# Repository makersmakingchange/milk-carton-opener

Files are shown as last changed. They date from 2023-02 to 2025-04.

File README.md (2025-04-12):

# Milk Carton Opener
The Milk Carton Opener is a 3D printed aid that enables users with limited grip strength to open tetra pak cartons, including 2L cartons such as the ones used for milk and juice.

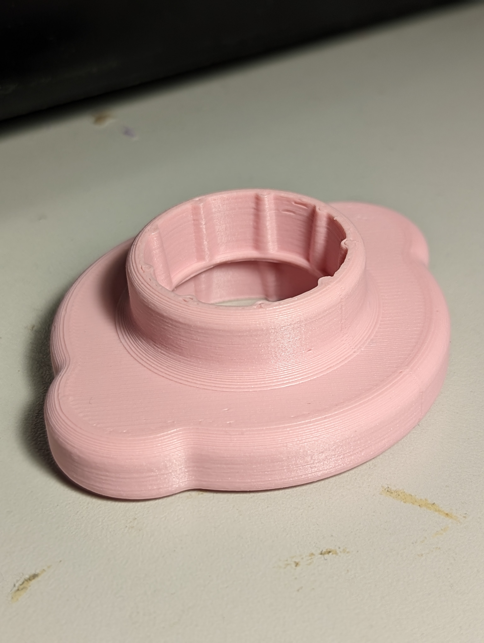
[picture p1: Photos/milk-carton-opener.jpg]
A pink 3-D printed Milk Carton Opener resting on a table.
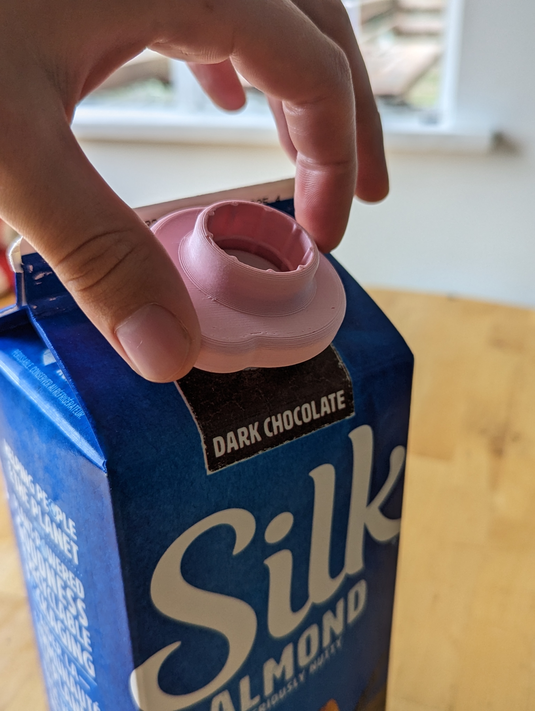
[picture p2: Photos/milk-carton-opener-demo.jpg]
Someone holding the Milk Carton Opener in their hand to remove the cap of a milk carton.
 

## More info at
- [Makers Making Change Project Page](https://makersmakingchange.com/project/milk-carton-opener/)

## How to Obtain a Milk Carton Opener
### 1. Do it Yourself (DIY) or Do it Together (DIT)

This is an open-source assistive technology, so anyone is free to build it. All of the files and instructions required to build the Milk Carton Opener are contained within this repository. Refer to the Maker Checklist below.

### 2. Request a build of this device

If you would like to obtain a Milk Carton Opener , you may submit a build request through the [MMC Library Page](https://makersmakingchange.com/project/milk-carton-opener/). The requestor is responsible for the cost of materials and any shipping.

### 3. How to build this device for someone else

If you have the skills and equipment to build this device, and would like to donate your time to create the switch for someone who needs it, visit the [MMC Maker Wanted](https://makersmakingchange.com/maker-wanted/) section.

## Getting Started

### 1. Read the Makers Checklist

The Makers' Checklist provides an overview of the necessary steps to build the device. 

### 2. Order the Off-The-Shelf Components

The [Bill of Materials](/Documentation/Milk_Carton_Opener_BOM_V1.0.xlsx) lists all of the parts and components required to print the Milk Carton Opener. 

### 3. Print the 3D Printable components

All of the files and individual print files can be in the [/Build_Files/3D_Printing_Files](/Build_Files/3D_Printing_Files/) folder.

### 4. Assemble the Milk Carton Opener

Reference the [Assembly Guide](/Documentation/Milk_Carton_Opener_Assembly_Guide_V1.0.pdf) for the tools and steps required to build each portion.

## Files
### Documentation
| Document | Version | Link |
|---|---|---|
| Design Rationale | 1.0 | [Milk_Carton_Opener_Design_Rationale](/Documentation/Milk_Carton_Opener_Design_Rationale_V1.0.pdf) |
| Maker Checklist | 1.0 | [Milk_Carton_Opener_Maker_Checklist](/Documentation/Milk_Carton_Opener_Maker_Checklist_V1.0.pdf) |
| Bill of Materials | 1.0 | [Milk_Carton_Opener_Bill_of_Materials](/Documentation/Milk_Carton_Opener_BOM_V1.0.xlsx) |
| 3D Printing Guide | 1.0 | [Milk_Carton_Opener_3D_Printing_Guide](/Documentation/Milk_Carton_Opener_3D_Printing_Guide_V1.0.pdf) |
| Assembly Guide | 1.0 | [Milk_Carton_Opener_Assembly_Guide](/Documentation/Milk_Carton_Opener_Assembly_Guide_V1.0.pdf) |
| User Guide | 1.0 | [Milk_Carton_Opener_User_Guide](/Documentation/Milk_Carton_Opener_User_Guide_V1.0.pdf) |
| Changelog | 1.0 | [Milk_Carton_Opener_Changelog](/Documentation/Milk_Carton_Opener_Changelog_V1.0.pdf) |

### Design Files
 - [CAD Files](/Design_Files)

### Build Files
 - [3D Printing Files](/Build_Files/3D_Printing_Files)

## Attribution
- Design by Tony Glynn
- Documentation by Neil Squire Society/Makers Making Change

## License

Everything needed or used to design, make, test, or prepare the Milk Carton Opener is licensed under the [Attribution-NonCommercial-ShareAlike 4.0 ](https://creativecommons.org/licenses/by-nc-sa/4.0/).

---
<!-- ABOUT MMC START -->
## About Makers Making Change
[Makers Making Change Logo](https://www.makersmakingchange.com/)

Makers Making Change is a program of [Neil Squire](https://www.neilsquire.ca/), a Canadian non-profit that uses technology, knowledge, and passion to empower people with disabilities.

Makers Making Change leverages the capacity of community based Makers, Disability Professionals and Volunteers to develop and deliver affordable Open Source Assistive Technologies.

 - Website: [www.MakersMakingChange.com](https://www.makersmakingchange.com/)
 - GitHub: [makersmakingchange](https://github.com/makersmakingchange)
 - Bluesky: [@makersmakingchange.bsky.social](https://bsky.app/profile/makersmakingchange.bsky.social)
 - Instagram: [@makersmakingchange](https://www.instagram.com/makersmakingchange)
 - Facebook: [makersmakechange](https://www.facebook.com/makersmakechange)
 - LinkedIn: [Neil Squire Society](https://www.linkedin.com/company/neil-squire-society/)
 - Thingiverse: [makersmakingchange](https://www.thingiverse.com/makersmakingchange/about)
 - Printables: [MakersMakingChange](https://www.printables.com/@MakersMakingChange)

### Contact Us
For technical questions, to get involved, or to share your experience we encourage you to [visit our website](https://www.makersmakingchange.com/) or [contact us](https://www.makersmakingchange.com/s/contact).
<!-- ABOUT MMC END -->

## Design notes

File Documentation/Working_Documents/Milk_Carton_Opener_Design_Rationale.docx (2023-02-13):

# Introduction

The Milk Carton Opener allows users with limited grip strength to open plastic 2L cartons such as the ones used for milk and juice.

# Research

Name | Picture | Price | Link

Commercial

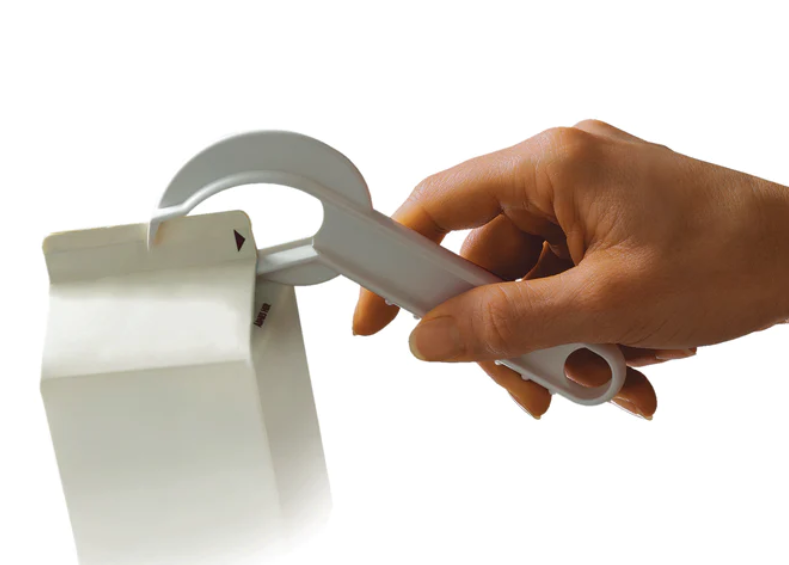
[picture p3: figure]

Tip Top Carton Opener | | $7.99 USD | Link (https://aidsforarthritis.com/products/tip-top-carton-opener)

DIY

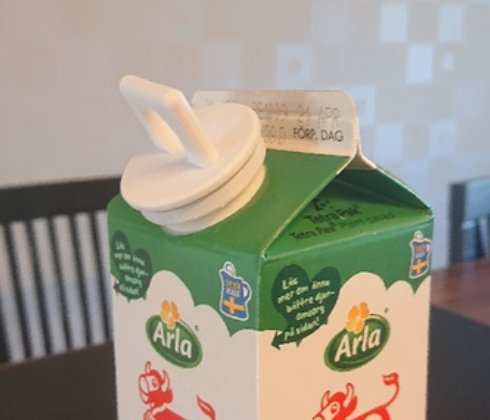
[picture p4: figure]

Milk Carton Opener | | N/A | Link (https://www.thingiverse.com/thing:4839483)

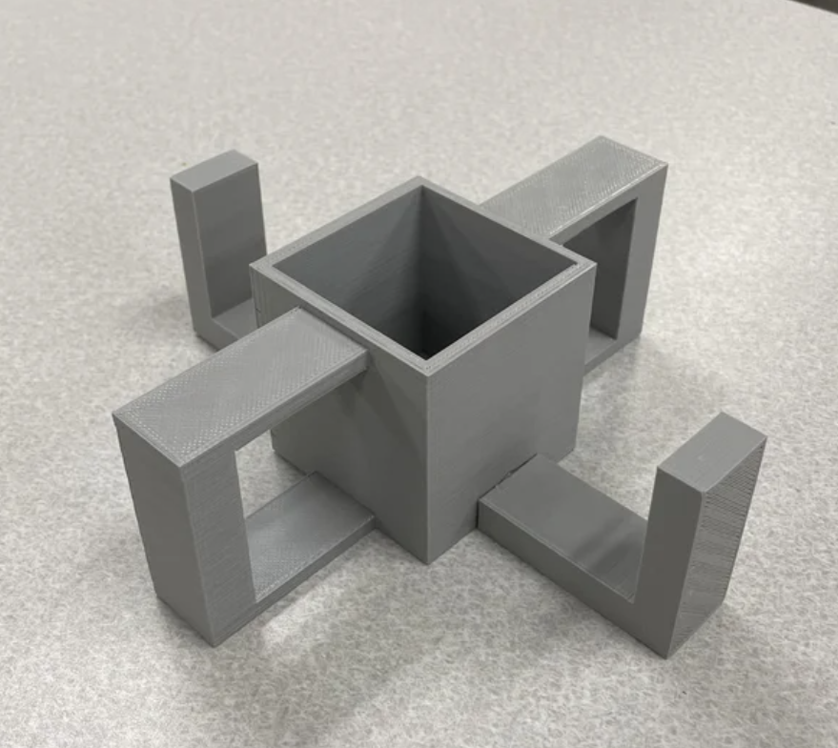
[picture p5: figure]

Milk Carton Opener | | N/A | Link (https://www.instructables.com/Milk-Carton-Opener/)

# Requirements

## Goals

G01 | Allow users with limited grip strength to open plastic milk cartons with twist off lids

## Functional Requirements

F01 | Work with both styles of plastic carton lids
F02 | Allow the lids to be removed with less force
F03 | Provide a better grip than the round lids of a carton

## Constraints

C01 | Must be entirely 3D printed

# Milk Carton Opener V1.0

## Design

This version of the design consists of a single 3D printed component with an outer handle and two differently sized gripping surfaces. The outside handle portion is cylindrical with two elongated portions to provide a gripping portion for the user’s hands. The inner gripping portions of the aids are slightly conical with rounded ribs around the periphery to provide better engagement with the screw cap.

## Print Testing

This design was test printed on a Prusa MK3S in PLA filament without support. The print was successful, though the inner portion has a bit of an unsupported lip and printed with poorer quality.

## Functional Testing

The device was tested on a Chocolate Silk Almond milk carton, and was easily able to remove the lid of the carton.

## Opportunities for Improvement

- Replace fillets on surface that lies on print bed with chamfer or mixed chamfer-fillet to improve print quality.
- Reconfigure geometry of the inner lip so device prints without support

© 2023 by Neil Squire. This work is licensed under the CC BY SA 4.0 License: http://creativecommons.org/licenses/by-sa/4.0 Files available at https://makersmakingchange.com/project/milk-carton-opener/ Page 1 of 1

V1.0 | January 2023 Milk Carton Opener Design Rationale

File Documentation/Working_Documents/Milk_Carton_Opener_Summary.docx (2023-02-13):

# Title

Milk Carton Opener

## Subtitle

An aid for people with limited grip strength to make it easier to open screwcap lids.

## Device Details

### Overview

The Milk Carton Opener is an aid to make it easier to open screwcap lids, such as those found on Tetra Pak cartons of milk, juice, and stock. This may be useful for people with limited dexterity or grip strength. The aid has two sides that fit two different sizes of cap.

### Usage

To use the device, place the hole in the device over the lid of the carton. This will provide a larger grip for the user on the lid of the carton so less grip force is required to open the lid.

### Cost

<$1

### Build Instructions

#### Skills Required

- 3D printing

#### Time Required

- 3D printing time: 1h46min
- Assembly time: None

#### Tools

- 3D printer
- Hobby knife

#### Components

- 1x Milk Carton Opener

### Attribution

- Design by Tony Glynn
- Documentation by Neil Squire Society/Makers Making Change

© 2023 by Neil Squire. This work is licensed under the CC BY SA 4.0 License: http://creativecommons.org/licenses/by-sa/4.0 Files available at https://makersmakingchange.com/project/milk-carton-opener/ Page 1 of 1

V1.0 | January 2023 Milk Carton Opener Summary

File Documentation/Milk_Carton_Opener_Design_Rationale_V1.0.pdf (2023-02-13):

V1.0 | January 2023

## Milk Carton Opener

## DESIGN RATIONALE

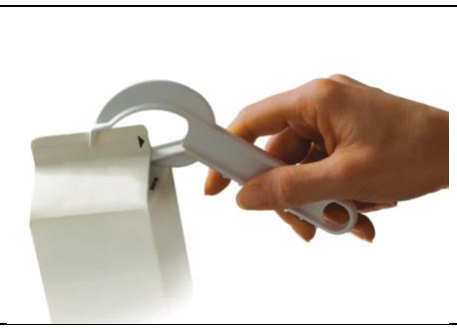
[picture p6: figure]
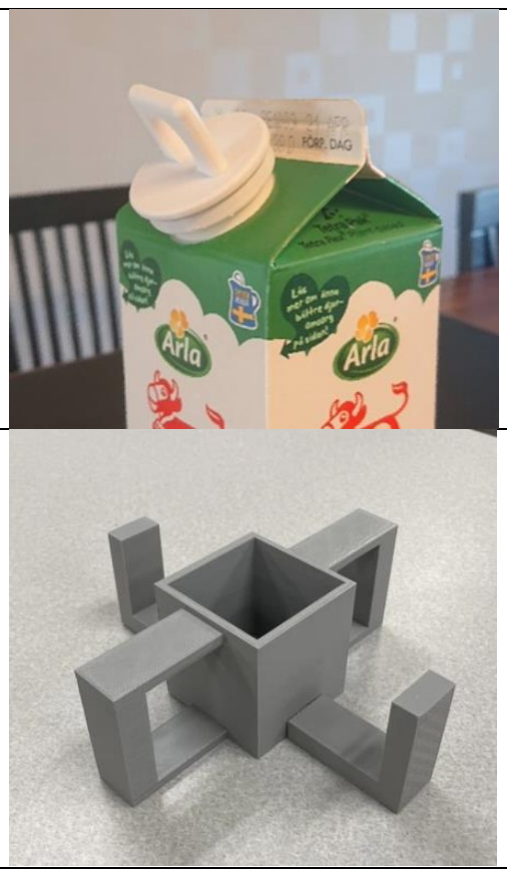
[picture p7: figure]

© 2023 by Neil Squire. (https://neilsquire.ca/)
This work is licensed under the CC BY SA 4.0 License: http://creativecommons.org/licenses/by-sa/4.0
Files available at https://makersmakingchange.com/project/milk-carton-opener/ | Page 1 of 3

### Introduction

The Milk Carton Opener allows users with limited grip strength to open plastic 2L cartons such as the ones used for milk and juice.

### Research

Name | Picture | Price | Link
Commercial
Tip Top Carton Opener | | $7.99 USD | Link (https://aidsforarthritis.com/products/tip-top-carton-opener)

DIY
Milk Carton Opener | N/A | Link (https://www.thingiverse.com/thing:4839483)
Milk Carton Opener | N/A | Link (https://www.instructables.com/Milk-Carton-Opener/)

## DESIGN RATIONALE

Files available at https://makersmakingchange.com/project/milk-carton-opener/ | Page 2 of 3

### Requirements

### Goals

G01 Allow users with limited grip strength to open plastic milk cartons with twist off lids

### Functional Requirements

F01 | Work with both styles of plastic carton lids
F02 | Allow the lids to be removed with less force
F03 | Provide a better grip than the round lids of a carton

### Constraints

C01 Must be entirely 3D printed

## DESIGN RATIONALE

Files available at https://makersmakingchange.com/project/milk-carton-opener/ | Page 3 of 3

### Milk Carton Opener V1.0

### Design

This version of the design consists of a single 3D printed component with an outer handle and two differently sized gripping surfaces. The outside handle portion is cylindrical with two elongated portions to provide a gripping portion for the user’s hands. The inner gripping portions of the aids are slightly conical with rounded ribs around the periphery to provide better engagement with the screw cap.

### Print Testing

This design was test printed on a Prusa MK3S in PLA filament without support. The print was successful, though the inner portion has a bit of an unsupported lip and printed with poorer quality.

### Functional Testing

The device was tested on a Chocolate Silk Almond milk carton, and was easily able to remove the lid of the carton.

### Opportunities for Improvement

- Replace fillets on surface that lies on print bed with chamfer or mixed chamfer-fillet to improve print quality.
- Reconfigure geometry of the inner lip so device prints without support

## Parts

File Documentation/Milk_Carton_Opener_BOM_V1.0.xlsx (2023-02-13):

Milk Carton Opener |  | Total Cost | Total Print time (hr) | Total filament (g)
Version: V1.0 | Last Updated: 20223-Jan-30 | $0.33 | 0.00 | 13
Commercial Parts:
Part type (Electrical. Mechanical, Sanitization, ect) | Part Name | Quantity Needed | Pkg Quantity | Price per package | Price per Unit | Price for qty needed | Link
n/a |  |  |  |  |  | $0.00
 |  |  |  |  |  | $0.00
3D Printed Parts ESTIMATED PRICING USING 1KG ROLL COST: | $25.00
Part | Description | Quantity Needed | TOTAL Mass (g) | Estimated Price | Print Time (Min) | Link
Milk Carton Opener.stl | Milk Carton Opener | 1 | 13 | $0.33
 |  |  |  | $0.00
 |  |  |  | $0.00
 |  |  |  | $0.00
 |  |  |  | $0.00
 |  |  | Total Print Cost: | $0.33
Tools for Assembly
Alternatives (if there are other sources for some parts link them below)
Part and description | Link

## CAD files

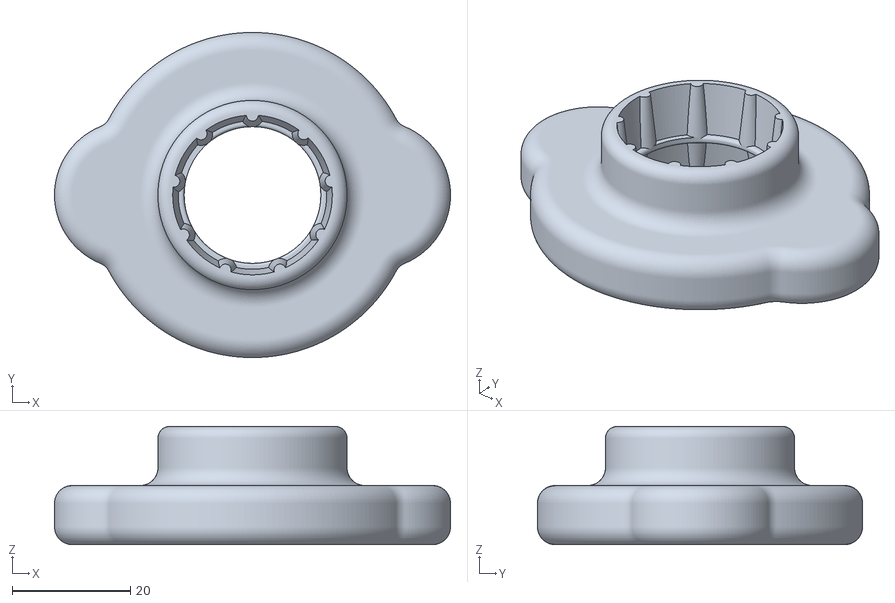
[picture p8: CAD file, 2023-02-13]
Build_Files/3D_Printing_Files/Milk-Carton-Opener.stl
67.0 x 55.0 x 20.0

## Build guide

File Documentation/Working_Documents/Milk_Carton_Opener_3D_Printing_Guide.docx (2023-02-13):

# 3D Printing Summary

Metrics | V1.0
Total Print Time (min) | 106
Total Number of Components | 1
Typical Total Mass (g) | 13
Typical Number of Print Setups | 1

# 3D Printing Settings

Print File Name | Qty | Total Print Time (hr:min) | Mass (g) | Infill (%) | Support(Y/N) | Layer Height/ Nozzle Diameter(mm) | Notes (orientation, special settings, etc.)
Milk-Carton-Opener.stl | 1 | 1:46 | 13 | 20 | Y | 0.2/0.4 | - Requires support

# Customization Options

- The device can be printed in any colour the user would like

# Post-Processing

- Remove all supports
- Use a hobby knife to remove any sharp edges

# Examples of Quality Prints

Photos of Opener

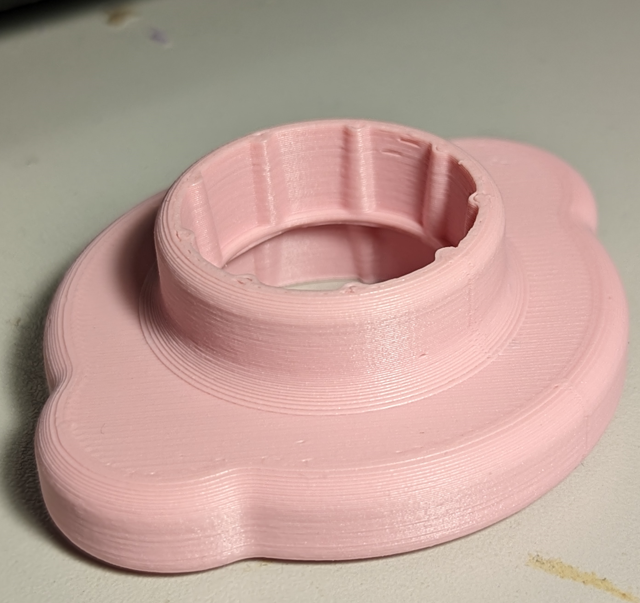
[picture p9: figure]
A Milk Carton Opener printed in light pink

© 2023 by Neil Squire. This work is licensed under the CC BY SA 4.0 License: http://creativecommons.org/licenses/by-sa/4.0 Files available at https://makersmakingchange.com/project/milk-carton-opener/ Page 1 of 1

V1.0 | January 2023 Milk Carton Opener 3D Printing Guide

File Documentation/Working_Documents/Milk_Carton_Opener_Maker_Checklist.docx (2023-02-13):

# Maker To Do List

- Read through the Assembly Guide to become familiar with required components, tools, supplies, and safety gear and overall assembly steps.
- Talk to User about customization options (e.g., color, any special requests, etc.)
- Gather tools, supplies, and safety equipment.
- Print the device
- Test device
- Print “User Quick Guide”

# Items to Give to User

- Assembled, tested device
- “User Quick Guide”

© 2023 by Neil Squire. This work is licensed under the CC BY SA 4.0 License: http://creativecommons.org/licenses/by-sa/4.0 Files available at https://makersmakingchange.com/project/milk-carton-opener/ Page 1 of 1

V1.0 | January 2023 Milk Carton Opener Maker Checklist

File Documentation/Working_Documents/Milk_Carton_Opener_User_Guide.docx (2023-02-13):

## Introduction

The Milk Carton Opener is an aid for people with limited grip strength to make it easier to open screwcap lids such as those found on aseptic carton packages like Tetra Pak® milk and juice cartons. The flat side of the aid is intended for larger caps aid has two sides for opening

## Features

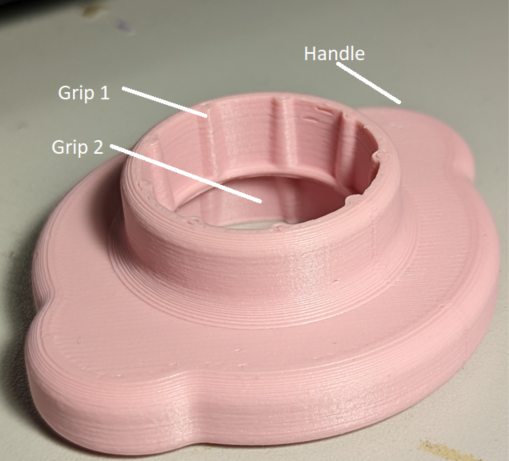
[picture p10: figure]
Labeled photo of the milk carton opener, showing both grips for different styles of lid, as well as the handles

## Usage

To use the device, place the hole in the device over the lid of the carton. Each side of the device has a different sized lid, so if it does not fit in one side, try the other. This will provide a larger grip for the user on the lid of the carton so less grip force is required to open the lid.

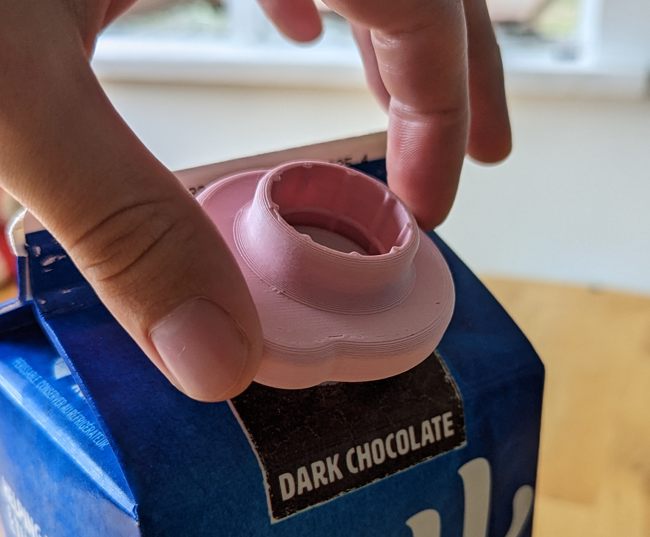
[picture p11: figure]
The milk carton opener being used to open a bottle of chocolate almond milk

## Compatibility

This device is compatible with two sizes of cardboard tetra pack lids.

## Specifications

Size: 55x65x20mm

Weight: 11g

## Cleaning

The device can be wiped clean with a damp cloth.

## Care

Do not expose the service to high heat (e.g., dishwasher)

© 2023 by Neil Squire. This work is licensed under the CC BY SA 4.0 License: http://creativecommons.org/licenses/by-sa/4.0 Files available at https://makersmakingchange.com/project/milk-carton-opener/ Page 1 of 1

V1.0 | January 2023 Milk Carton Opener user Quick Guide

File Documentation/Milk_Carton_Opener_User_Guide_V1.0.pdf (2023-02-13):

V1.0 | January 2023

## Milk Carton Opener

## USER QUICK GUIDE

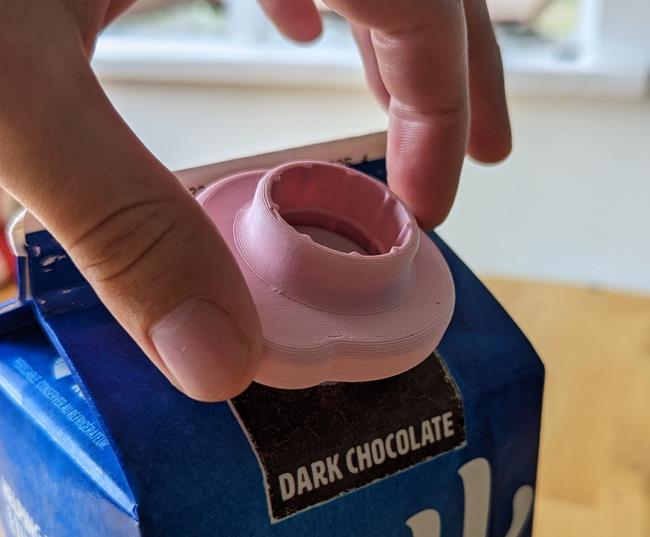
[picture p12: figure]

© 2023 by Neil Squire. (https://neilsquire.ca/)

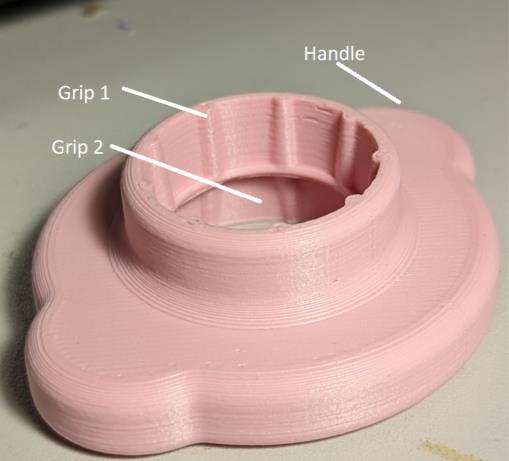
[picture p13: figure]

This work is licensed under the CC BY SA 4.0 License: http://creativecommons.org/licenses/by-sa/4.0
Files available at https://makersmakingchange.com/project/milk-carton-opener/ | Page 1 of 2

### Introduction

The Milk Carton Opener is an aid for people with limited grip strength to make it easier to open screwcap lids such as those found on aseptic carton packages like Tetra Pak® milk and juice cartons. The flat side of the aid is intended for larger caps aid has two sides for opening

### Features

### Usage

To use the device, place the hole in the device over the lid of the carton. Each side of the device has a different sized lid, so if it does not fit in one side, try the other. This will provide a larger grip for the user on the lid of the carton so less grip force is required to open the lid.

V1.0 | January 2023

## Milk Carton Opener

## USER QUICK GUIDE

© 2023 by Neil Squire. (https://neilsquire.ca/)
This work is licensed under the CC BY SA 4.0 License: http://creativecommons.org/licenses/by-sa/4.0
Files available at https://makersmakingchange.com/project/milk-carton-opener/ | Page 2 of 2

### Compatibility

This device is compatible with two sizes of cardboard tetra pack lids.

### Specifications

Size: 55x65x20mm

Weight: 11g

### Cleaning

The device can be wiped clean with a damp cloth.

### Care

Do not expose the service to high heat (e.g., dishwasher)

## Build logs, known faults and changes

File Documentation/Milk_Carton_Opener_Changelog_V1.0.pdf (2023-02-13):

V1.0 | January 2023

# Milk Carton Opener

# CHANGELOG

© 2023 by Neil Squire. (https://neilsquire.ca/)
This work is licensed under the CC BY SA 4.0 License: http://creativecommons.org/licenses/by-sa/4.0
Files available at https://makersmakingchange.com/project/milk-carton-opener/ | Page 1 of 1

# Version 1.0 | 2023/01/27

## - Design by Tony Glynn - Documentation by Neil Squire Society/Makers Making Change

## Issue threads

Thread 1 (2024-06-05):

When using grip 2 the flanges of the opener hit  the top of the milk carton

MHache1717, 2024-06-05:
Can still be used as long as the opener isn't engaged fully on the cap. Wondering if we can modify somehow ? We could elongate grip 2 to protrude out the bottom but that would introduce more support requirements.

If you want to shoot me the source files I can play with it.

jakemcivor, 2024-06-05:
Unfortunately, there is no source CAD files for this device. Only the stl was included in the submission to the site. I've created a complimentary issue: https://github.com/makersmakingchange/milk-carton-opener/issues/2

I've reached out to the original designer. There are also a few folks that have volunteered to take on recreating designs in Fusion, so that is another option.  This is a fairly simple design, so should be a pretty straightforward one to recreate.

MHache1717, 2024-06-05:
Might be an easier fix than I thought, I think we just need to make the ring a little thinner. You're right it's an easy design to reproduce. I'll plan around with it
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
